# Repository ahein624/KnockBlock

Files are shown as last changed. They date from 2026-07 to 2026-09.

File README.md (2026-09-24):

# AH.knockblock

A phone-controlled office status sign. Tap a button on your phone; the status
instantly shows on two vertically stacked 64×32 HUB75 LED panels, driven as
one 64×64 display by a Raspberry Pi 4.

## Quick start

On a fresh Raspberry Pi with the panel wired up (see [Hardware](#hardware)):

```bash
curl -sSL https://raw.githubusercontent.com/ahein624/KnockBlock/main/install.sh | bash
```

The installer clones the code, builds the panel driver, and installs the
`knockblock` systemd service (it may ask you to reboot once for the audio
change, then re-run). When it finishes, open `http://<pi-ip>:5000` from a
phone on the same WiFi to **claim your sign**: set a password, name it, and
you're live. Re-running the installer later is the upgrade path — it never
touches your password, state, or uploaded media.

Prefer to see every step, or debugging a panel? The full walkthrough is in
[Manual setup](#setup-step-by-step).

## Features

- **Status presets** with emoji icons (On a Call, Free, In a Meeting, Do Not
  Disturb), rendered with auto-fitted text on the panel
- **Custom messages** — type anything (leading emoji becomes the icon), pick a
  background color; recent messages become one-tap chips
- **Custom statuses** — build your own status buttons (up to 8) from text,
  an uploaded image/meme/GIF, or both. Images can play bare or carry a text
  caption; image-only buttons take their name from the file or GIF title.
  They join the status grid with real-render thumbnails, work
  from the Stream Deck (`/api/set/cs_…`), and deleting one that's showing
  releases to auto
- **Auto-revert timers** — "On a Call for 30 min, then back to Free," with a
  live countdown; changing the status keeps the original expiration, even
  across a reload. The phone remembers the selected duration for the next
  hold, and “Forever” has no expiration
- **Live preview** — the phone UI mirrors exactly what the panel shows
- **Device temperature** — Settings shows the Pi CPU temperature in °F
- **Clock & weather screen** — a tappable mode showing the local time plus
  current conditions; outside working hours an idle sign switches to it
  automatically (Open-Meteo, no API key; location auto-detected from the
  Pi's public IP, overridable via settings lat/lon; time follows the Pi's
  system timezone)
- **Brightness control**, **state persistence** across power cycles, and a
  **PWA** phone UI (Add to Home Screen for a full-screen app)
- **Themes** — per-device, in Settings → Appearance: *Glass* (dark,
  translucent, modern), *Workshop* (the warm house style), or *Clear*
  (high-contrast, plain, accessibility-first). Stored in a cookie the
  server reads, so pages load in your theme with no flash
- **Panel styles** — sign-wide, in Settings → Panel style: *Classic* flat
  cards, *Nameplate* (skeuomorphic brushed-metal shop plates — beveled
  edges, corner screws, engraved text, a glowing indicator lamp in the
  status color), *Terminal* (green-phosphor console with scanlines), or
  *8-bit* (pixel icon cards — headset, sun, meeting heads, do-not-enter —
  with the clock and focus screens drawn to match: sun or moon by hour,
  hourglass timer). All original art; the status buttons preview whichever
  is active
- **Password login** — everything (UI and API) requires either a logged-in
  browser session or the API token, so the sign can be exposed beyond the LAN
- **API token for scripts** — one-URL status changes from a Stream Deck,
  Apple Shortcuts, or curl (see below)
- **Screen off** — a prominent “Turn off screen for the day” control below
  the live preview (plus the header shortcut) turns the panel fully dark on
  demand and keeps it off until you turn it back on. It's a top-priority
  manual hold, so it overrides the schedule and whatever's showing; tapping
  any status (or the badge) wakes it. Also at `/api/set/screen_off` for a
  Stream Deck "lights out" button
- **Sleep schedule** — the panel goes dark every night during a configurable
  window (e.g. 22:00–07:00) whenever it's idle; a deliberately set status or
  the manual screen-off override still win. Or pick **Moonlight** instead of
  dark: a very dim night scene — crescent moon, twinkling stars, and a
  sleeping cat exhaling z's
- **On-a-call autodetect** — a tiny agent on your laptop watches the
  camera/mic (macOS via OverSight, Windows via the ConsentStore registry)
  and heartbeats the sign; a 15s watchdog clears the status if the agent
  dies mid-call
- **Focus timer** — 15/25/50-minute buttons; the panel shows FOCUS with a
  live MM:SS countdown, then releases automatically
- **Calendar** — point it at a Google Calendar secret iCal address (no
  OAuth) and the sign shows "In a Meeting" during events, recurring ones
  included
- **GIFs & images** — search Tenor/Giphy and pick from a grid of results,
  or hit Roll for a random one; picks work as panel screens and as custom
  status backgrounds, and you can upload any image or animated GIF from the
  phone. Media rides the manual-hold rules, so the hold TTL and timer chips
  keep a joke from becoming your all-day status. Picked results only ever
  download from the providers' own CDNs. The old public demo keys have gone
  stale, so put a personal (free) key in `auth.json`:
  `{"giphy_key": "..."}` — it's tried first
- **Screen designer** — a pixel editor for the active panel size right in the
  phone UI: draw, flood-fill, undo, start from what the sign is showing,
  save favorites on the device, and send to the panel (rides the same
  manual-hold rules as uploads)
- **Dumpster fire mode** — one tap plays an original procedurally-animated
  "THIS IS FINE." flame scene (no meme copyright, works offline); also at
  `/api/set/dumpster_fire` for a Stream Deck panic button
- **Arcade mode** — an original retro-platformer loop drawn pixel by pixel:
  scrolling bricks, pipes, blinking coins, and a little runner in KnockBlock
  orange who jumps the pipes (no licensed sprites, works offline); also at
  `/api/set/arcade`
- **Demo mode** — share `/demo` and visitors watch the real sign live
  (state, preview, countdowns) but every write is refused with a polite
  quip; secrets (calendar URL, location, API token) are redacted and the
  settings sheet is hidden. Logging in normally exits demo mode
- **Scheduled statuses** — recurring rules like "Lunch, 12:00–13:00,
  Mon–Fri" the sign follows on its own. A rule can show **any screen** — a
  preset, the clock, dumpster fire, arcade, or one of your own custom/GIF
  screens — with overnight windows included. A manual tap overrides; Auto
  resumes
- **Weekly insights** — a "This week" panel with time spent in meetings,
  calls, and focus, from an append-only local history (three months kept,
  message text never logged)
- **First-run claim wizard** — a fresh sign is claimed from a phone on its
  own WiFi: password, name, work hours, API token. No SSH needed
- **Self-update** — an "Update sign" button pulls the latest code, restarts,
  and rolls itself back if the sign doesn't come back up
- **Priority arbiter** — when several sources are active at once:
  manual hold → on-call → focus → calendar → schedule → idle. Manual
  presses release after a configurable TTL (default 2h) so a tapped button
  can't suppress autodetect all day; the Auto button releases a hold early

## Login & security

A fresh sign is **claimed** from its own network: open `http://<pi-ip>:5000`
from a phone on the sign's WiFi and the first-run wizard asks for a
password, a name, and your work hours. The wizard only answers LAN clients
and only while no password exists, so an internet-exposed unclaimed sign
still can't be seized by a stranger. From a terminal (also the only way to
*reset* a forgotten password):

```bash
sudo ./venv/bin/python3 app.py --set-password
```

Claiming also reveals the **API token** used by scripted clients
(`--show-token` reprints it; the phone UI shows it too, with a regenerate
button). Logins get a long-lived session cookie — right for a personal PWA.
Repeated failed logins back off with a per-IP lockout.

**LAN clients skip the password entirely.** A request counts as local only
when every check agrees: the TCP source address is private, no forwarding
headers (`X-Forwarded-For`, `X-Real-IP`, `CF-*`) are present, the source
isn't a known reverse proxy, and the request isn't addressed to the public
hostname. Public traffic that reaches the sign through a proxy on the same
LAN therefore still needs the password. Two optional keys in `auth.json`
configure the site-specific parts:

```json
{"public_host": "sign.example.com", "untrusted_proxies": ["192.168.1.5"]}
```

Set `untrusted_proxies` to the LAN address(es) of whatever relays outside
traffic to the sign (reverse proxy, tunnel daemon), and `public_host` to the
domain it serves.

If you expose the sign to the internet, put it behind HTTPS (a reverse proxy
like Caddy, or a Cloudflare tunnel) — over plain HTTP the password and token
travel in the clear. A Tailscale/VPN-only setup avoids the exposure entirely.

## Remote access

The recommended way to reach the sign away from home is **Tailscale** — no
port forwarding, no reverse proxy, no exposed attack surface:

1. On the Pi: `curl -fsSL https://tailscale.com/install.sh | sh`, then
   `sudo tailscale up`.
2. Install the Tailscale app on your phone and sign in to the same tailnet.
3. Visit `http://<pi-tailscale-name>:5000` (MagicDNS) from anywhere. For
   HTTPS — which lets the phone use the clipboard API and installs more
   cleanly as a PWA — run `sudo tailscale serve --bg 5000` and use the
   `https://…ts.net` URL it prints.

One deliberate quirk: Tailscale addresses live in `100.64.0.0/10`, which is
*not* a private range, so tailnet clients are asked for the password like
any other remote visitor. That's the safe default — anyone you share your
tailnet with shouldn't automatically control your door.

The advanced alternative — a public domain through a reverse proxy or
Cloudflare tunnel — works with the `public_host` / `untrusted_proxies` keys
above; that's how the original sign runs. WiFi captive-portal provisioning
(configuring the Pi's WiFi from the phone) is future work; for now the Pi
joins WiFi the usual way (Raspberry Pi Imager presets or `nmtui`).

## API

Everything the UI does goes through JSON endpoints, so you can script it.
Authenticate with `Authorization: Bearer <token>`, an `X-Api-Token` header,
or `?token=<token>`:

- `GET /api/state` — what's showing and why (`status`, `source`, `held`),
  plus brightness, recents, focus/calendar state, schedules, settings,
  weather
- `POST /api/state` — any subset of:
  `{"status": "free" | "on_a_call" | ... | "clock" | "auto"}` (`auto`
  releases a manual hold),
  `{"message": {"text": "...", "color": "blue"}}`,
  `{"focus_minutes": 25}` (0 cancels),
  `{"brightness": 5-100}`, `{"revert_minutes": N}` (with a status/message;
  0 means forever), `{"preserve_hold": true}` (keep an active hold's absolute
  expiration while changing its status),
  `{"settings": {"sign_name": "Knockblock", "weather_idle": true,
  "work_start": "08:00", "work_end": "18:00", "units": "f", "lat": null,
  "lon": null, "sleep_enabled": true, "sleep_start": "22:00",
  "sleep_end": "07:00", "ical_url": "https://…",
  "manual_ttl_minutes": 120}}`,
  `{"schedules": [{"label": "Lunch", "status": "custom",
  "message": {"text": "Back at 1", "color": "orange"}, "start": "12:00",
  "end": "13:00", "days": [0,1,2,3,4], "enabled": true}]}` — full-list
  replace; `status` is a preset key, `"clock"`, or `"custom"` (which
  requires `message`); `start > end` spans midnight; first matching rule
  wins
- `GET /api/insights?days=7` — seconds per status per local day plus
  totals, from the on-device history (max 31 days; blocked in demo mode)
- `POST /api/statuses` — create a custom status (multipart: `text`, and
  `bg_color` or an image/GIF `file`); `DELETE /api/statuses/<id>` removes
  one (releasing the sign if it's showing). Set them like any status:
  `{"status": "cs_…"}` or `/api/set/cs_…`
- `POST /api/oncall` — `{"active": true|false}` heartbeat from a laptop
  sensor; the status clears itself 15s after the last `true`
- `GET /api/gif/search?q=…` — GIF candidates: `[{"url", "preview", "title"}]`
- `POST /api/gif` — `{"url": "...", "title": "..."}` shows a search pick
  (provider CDNs only), or `{"query": "dancing cat"}` for a random one;
  `revert_minutes` optional on both
- `POST /api/upload` — multipart `file` (image or GIF) plus optional
  `revert_minutes`; shows it on the panel
- `GET|POST /api/set/<status>` — one-URL change for buttons:
  `/api/set/on_a_call?minutes=30`, `/api/set/focus?minutes=25`,
  `/api/set/dumpster_fire`, `/api/set/auto`
- `POST /api/update` / `GET /api/update/status` — start the self-updater /
  watch its progress. Session or LAN only, like `GET|POST /api/token` —
  a leaked API token can't swap code or read credentials
- `GET /preview.png` — PNG of what the panel currently shows

## On-call laptop sensors

Both agents heartbeat `POST /api/oncall` every 5s while the camera or mic
is in use, so a crashed agent just times out after 15s.

**macOS** — install [OverSight](https://objective-see.org/products/oversight.html),
then in OverSight's settings set *Execute Action* to
`agents/oversight-knockblock.sh` (copy it anywhere) and enable *pass
arguments*. Edit the script's `SIGN_URL`/`TOKEN` lines or export
`KNOCKBLOCK_URL`/`KNOCKBLOCK_TOKEN`.

**Windows** — run `agents/knockblock-sensor.ps1` at logon (see the
`schtasks` one-liner in the script header). It polls the same registry keys
Windows uses for the camera/mic tray indicators.

Neither agent needs the token while the laptop is on the sign's LAN, but
set it anyway so the buttons keep working from anywhere.

## Stream Deck

Any Stream Deck action that can hit a URL works — no custom plugin needed.
With the stock **System → Website** action (or the "API Ninja" / "Web
Requests" plugins if you'd rather POST without opening a browser), point a
button at:

```
http://<sign-host>:5000/api/set/on_a_call?token=<your-token>
```

Add `&minutes=30` for "On a Call for 30 minutes, then back to Free". The
same URLs work from Apple Shortcuts ("Get Contents of URL") or cron.

## Hardware

- Raspberry Pi 4 Model B
- Two Waveshare 64×32 HUB75 RGB LED matrix panels, stacked vertically and
  daisy-chained from the first panel's output to the second panel's input
- Generic HUB75 adapter board plugged into the 40-pin GPIO header (no HAT
  level-shifter IC)
- A separate 5V power supply sized for both panels (at least 8A, with power
  delivered to both panels and a common ground). **Do not** power either panel
  from the Pi's 5V pins — the panels can draw more current than the Pi can
  safely supply, and both will brown out.

The app defaults to the two-panel 64×64 layout. It configures a chain length of
2 and the driver's `V-mapper`, with both panels mounted right-side up. To run
the original single-panel 64×32 layout, set `KNOCKBLOCK_PANEL_COUNT=1` in the
service environment before starting KnockBlock. The API, live preview,
thumbnails, uploads, animations, and screen designer all use the active size.

Building an enclosure for the stacked panels? The repository includes a
[parametric case, dimensioned drawing, diffuser specification, and assembly
guide](hardware/case/README.md).

### Two-panel wiring and configuration

Mount both panels right-side up, one above the other. The first panel is the
top half of the finished sign:

```text
Raspberry Pi HUB75 adapter
          │
          ▼
┌────────────────────┐
│ Top panel      IN   │  64×32
│              OUT ──┼────────┐
└────────────────────┘        │
                              ▼
┌────────────────────┐
│ Bottom panel   IN   │  64×32
└────────────────────┘

Logical canvas: 64×64
```

Power both panels directly from the 5V supply. Do not carry panel power
through the Pi or through the HUB75 ribbon cable. Connect the Pi/adapter and
both panels to a common ground. With two panels, inject power into each panel
rather than relying on one panel's power connector to feed the other.

No software setting is needed for the normal two-panel arrangement. On start,
KnockBlock configures the driver with these effective options:

| Option | Value | Purpose |
| --- | --- | --- |
| Physical panel | 64 columns × 32 rows | Size of each Waveshare module |
| Chain length | `2` | Top panel output feeds the bottom panel input |
| Parallel chains | `1` | One HUB75 data chain from the Pi |
| Pixel mapper | `V-mapper` | Presents the horizontal hardware chain as 64×64 |

After wiring the second panel, update and restart the sign, then open Settings.
**Panel style → Display** should read `64×64 · 2 panels`. The live preview and
screen designer should both be square. For a hardware-only check, stop the
service and run:

```sh
sudo systemctl stop knockblock
sudo ./venv/bin/python3 hello_matrix.py
# Press Ctrl+C after checking both halves.
sudo systemctl start knockblock
```

To keep using one panel, add a systemd override:

```sh
sudo systemctl edit knockblock
```

```ini
[Service]
Environment=KNOCKBLOCK_PANEL_COUNT=1
```

Then apply it:

```sh
sudo systemctl daemon-reload
sudo systemctl restart knockblock
```

Remove that override, or change the value to `2`, before moving back to the
stacked display. `KNOCKBLOCK_PANEL_COUNT` accepts only `1` or `2`; an invalid
value deliberately prevents startup instead of driving an unknown layout.

## Updating

Settings → Software → **Update sign** pulls the latest code, restarts the
service, and health-checks itself — if the sign doesn't come back up it
rolls back to the version that worked and says so. Under the hood it's
`scripts/update.sh` run as a transient systemd unit; your password, state,
history, and uploaded media are untracked files the update never touches.
Re-running `install.sh` does the same job from a shell.

## Project layout

- `app.py` — Flask web server; exposes the phone UI and the JSON API
- `auth.py` — password + API-token auth, backed by `auth.json` (not in git)
- `matrix.py` — wraps `rpi-rgb-led-matrix` to render a preset (text + colors) to the panel
- `presets.py` — the status screens (label, text lines, colors) shown as phone buttons
- `history.py` — append-only status history + the insights aggregation
- `templates/` — the phone UI, login, and first-run claim wizard
- `install.sh` / `deploy/` — one-command installer and the systemd unit
- `scripts/update.sh` — the self-updater (fetch, swap, health-check, roll back)
- `hello_matrix.py` — standalone smoke test, no Flask required
- `requirements.txt` — Python deps installed via pip (Flask, Pillow)
- `dev/` — hardware-free dev server (stubbed panel) for UI work

## Development (no hardware needed)

Everything except the physical panel runs on any machine:

```bash
python3 -m venv venv
./venv/bin/pip install -r requirements.txt
./venv/bin/python3 dev/dev_server.py
```

Open http://127.0.0.1:5099 and log in with `devpassword1`. Runtime files
live in `dev/state/` (gitignored), so a real sign's `auth.json` and
`state.json` are never touched. The dev server poses as a public client
so the login and demo flows are exercisable; see the switches documented
at the top of `dev/dev_server.py` (`KNOCKBLOCK_DEV_LOCAL`,
`KNOCKBLOCK_DEV_UNCLAIMED`, `KNOCKBLOCK_DEV_FRESH`).

## Setup, step by step

### 1. Disable onboard audio

The Pi's onboard audio uses the same PWM hardware the LED matrix needs for
clean timing; leaving it enabled causes flicker and ghosting.

Edit the boot config (`/boot/firmware/config.txt` on newer Raspberry Pi OS,
or `/boot/config.txt` on older releases) and comment out or remove the audio
line:

```
# dtparam=audio=on
```

**This requires a reboot** (`sudo reboot`) to take effect.

### 2. Install the driver (hzeller/rpi-rgb-led-matrix)

Current Raspberry Pi OS (Debian trixie) blocks system-wide `pip install`
(PEP 668), so everything Python-related lives in a virtualenv inside the
project folder:

```bash
sudo apt-get update
sudo apt-get install -y git python3-dev python3-pip cython3
git clone https://github.com/hzeller/rpi-rgb-led-matrix.git ~/rpi-rgb-led-matrix
cd ~/KnockBlock
python3 -m venv venv
./venv/bin/pip install --upgrade pip
```

The current version of the driver builds via `pyproject.toml`/CMake and
needs Pillow's internal `Imaging.h` C header, which isn't vendored in the
repo. Install Pillow first, then fetch the matching header (and its own
few includes) into the bindings' `shims/` folder before building:

```bash
./venv/bin/pip install Pillow Flask
PILLOW_VERSION=$(./venv/bin/python3 -c "import PIL; print(PIL.__version__)")
cd ~/rpi-rgb-led-matrix/bindings/python/rgbmatrix/shims
for f in Imaging.h ImPlatform.h Mode.h Arrow.h ImagingUtils.h; do
  curl -sSL -o "$f" "https://raw.githubusercontent.com/python-pillow/Pillow/$PILLOW_VERSION/src/libImaging/$f"
done
cd ~/KnockBlock
./venv/bin/pip install ~/rpi-rgb-led-matrix
```

### 3. Install remaining Python deps

Flask and Pillow already went into the venv above (needed there for the
driver's header check); nothing else is required for `requirements.txt`.

### 4. Confirm the driver imports

```bash
./venv/bin/python3 -c "import rgbmatrix; print('ok')"
```

If this fails, the Python bindings didn't build/install correctly — re-run
step 2 and check the build output.

### 5. Light up a static test screen

Before touching the web app, isolate hardware issues with the standalone
test script. It needs `sudo` for GPIO access:

```bash
sudo ./venv/bin/python3 hello_matrix.py
```

You should see "HELLO" / "KNOCKBLOCK" in green text on the panel.

### 6. Hardware troubleshooting

If the test screen is blank, garbled, flickery, or has wrong colors, adjust
these options in `matrix.py` one at a time and re-run `hello_matrix.py`:

| Symptom | Try |
| --- | --- |
| Panel is completely blank | Check the panel's own power supply is on and wired to the panel (not just the Pi); confirm the ribbon cable orientation; try `hardware_mapping = "adafruit-hat"` if your adapter board has a level-shifter chip |
| Top panel works but bottom panel is blank | Confirm the second panel has its own 5V power connection; check the ribbon from the top panel's `OUT` connector to the bottom panel's `IN`; confirm `KNOCKBLOCK_PANEL_COUNT` is not set to `1` |
| Two halves appear beside each other or only half the picture is useful | Confirm the installed code includes `pixel_mapper_config = "V-mapper"`; Settings should report `64×64 · 2 panels` |
| The top and bottom content are reversed | The panel connected directly to the Pi is the first/top panel. Swap the panel data order, not the power wiring |
| Image is garbled / scrambled pixels | Increase `gpio_slowdown` (try 2, then 3, then 4) — the Pi is driving the GPIO faster than the panel can latch |
| Flickering or dim/ghosting rows | Increase `gpio_slowdown`; confirm onboard audio is disabled (step 1) |
| Colors are swapped (e.g. red/blue flipped) | Change `led_rgb_sequence` from `"RGB"` to `"RBG"`, `"GRB"`, etc. until colors match |

### 7. Set the login password

```bash
sudo ./venv/bin/python3 app.py --set-password
```

Note the API token it prints if you plan to script the sign.

### 8. Run the web app

```bash
sudo ./venv/bin/python3 app.py
```

Find the Pi's IP address with `hostname -I`, then on your phone (same WiFi),
visit `http://<pi-ip-address>:5000`, log in, and tap a button — the panel
should update immediately.

### 9. Auto-start on boot (systemd)

Create `/etc/systemd/system/knockblock.service` (adjust `WorkingDirectory` and
`User` if your project lives somewhere other than `/home/ahein/KnockBlock`):

```ini
[Unit]
Description=KnockBlock status sign
After=network.target

[Service]
Type=simple
WorkingDirectory=/home/ahein/KnockBlock
ExecStart=/home/ahein/KnockBlock/venv/bin/python3 /home/ahein/KnockBlock/app.py
Restart=on-failure
User=root

[Install]
WantedBy=multi-user.target
```

The service runs as `root` because the LED matrix library needs raw GPIO
access, same as the `sudo` used above.

Enable and start it:

```bash
sudo systemctl daemon-reload
sudo systemctl enable knockblock
sudo systemctl start knockblock
```

Check status and logs:

```bash
sudo systemctl status knockblock
sudo journalctl -u knockblock -f
```

## Future work

- **WiFi captive-portal provisioning** — claim a sign that isn't on WiFi
  yet, straight from the phone; today the Pi joins WiFi via the Raspberry
  Pi Imager presets or `nmtui`
- **Tailnet-as-local option** — an opt-in `trusted_networks` key so tailnet
  clients skip the password like LAN clients do
- **Drag-to-reorder schedules** — priority is list order; today it's
  up-arrows

---

*Practical over decorative.*

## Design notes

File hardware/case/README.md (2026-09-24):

# Dual-panel case

This enclosure holds two Waveshare RGB-Matrix-P2.5-64x32 panels vertically so
they read as one 64×64 display. It is sized for the panel sold under Amazon
ASIN `B0BRBGHFKQ`: each module is nominally 160 × 80 mm and about 14.5 mm
deep.

The design does not use the panels' rear mounting holes because the published
specification does not provide their coordinates. The panels sit in a
perimeter cradle and are held with movable clips instead. Measure both of your
panels before committing to a full print.

Dimensioned case drawing

## Design summary

| Item | Nominal dimension |
| --- | ---: |
| Finished face | 180 × 180 mm |
| Finished depth | 62 mm |
| Combined panel face | 160 × 160 mm |
| Panel pocket | 161 × 161 × 16 mm |
| Diffuser | 164 × 164 × 2 mm, 8 mm corner clips |
| Diffuser-to-LED gap | 10 mm |
| Front bezel | 4 mm deep |
| Optical spacer | 10 mm deep |
| Panel cradle | 16 mm deep |
| Rear electronics shell | 32 mm deep |

All dimensions are parameters near the top of
[`knockblock_case.scad`](knockblock_case.scad). The 180 mm square parts fit on
a typical 220 × 220 mm printer bed.

### What to measure first

Use calipers and update the matching parameters in the CAD file:

1. Measure the width and height of both panels. Use the larger value plus
   0.6–1.0 mm for `panel_pocket`.
2. Measure from the LED face to the tallest rear component. Include any power
   plug or ribbon-cable bend that must sit inside the cradle.
3. Measure the actual diffuser thickness. Give its pocket 0.3–0.5 mm of total
   clearance.
4. Lay out the Pi, HUB75 adapter, and cables in the 174 × 174 × 29 mm usable
   rear cavity. Increase `electronics_depth` if the cable bend needs it.

The most important test is the pocket fit. Export and print `fit_coupon`
before printing the full case.

## Parts

### Printed parts

- 1 × `bezel`
- 1 × `spacer`
- 1 × `cradle`
- 1 × `back_shell`
- 1 × `diffuser` only when printing the diffuser instead of cutting opal sheet
- 6–8 × `retainer_clip`
- 1 × `fit_coupon` before the production print

PETG or ASA is preferred. Black material prevents light leaking through the
case. PLA can work for a prototype, but the rear cavity contains a Raspberry
Pi and should not be allowed to soften in a warm room.

Suggested starting settings: 0.2 mm layers, four perimeters, five top/bottom
layers, and 25% infill. Print the flat frames face-down. Orient the back shell
with its wall-facing panel on the build plate. The model avoids large internal
supports, although a printer may request small supports at the bottom cable
notch.

### Purchased parts

- 1 × 164 × 164 × 2 mm opal lighting acrylic or polycarbonate diffuser,
  with each corner clipped 8 × 8 mm to clear the face screws
- 4 × M3 × 35 mm black countersunk machine screws for the face
- 4 × M3 heat-set inserts, sized to match the CAD's 4.2 mm insert holes
- 6–8 × M3 × 8 mm screws and matching inserts for the panel clips
- 1–2 mm self-adhesive closed-cell foam for the clips
- 2 × suitable wall screws and anchors
- 4 × 5 mm rubber wall bumpers to preserve airflow behind the rear vents
- Low-voltage cable strain relief or grommet for the 20 × 10 mm bottom entry

The face screws are intentionally visible and serviceable. If a clean face is
more important than tool-free alignment, move the four fasteners to the sides
before printing.

## Diffuser

A 2 mm opal sheet with roughly 30–50% light transmission is a practical
starting point. The 10 mm air gap is four times the 2.5 mm pixel pitch, which
usually blends adjacent pixels while keeping text reasonably sharp. That gap
is a design recommendation, not a manufacturer specification.

For a printed prototype, open
[`stl/knockblock_diffuser.3mf`](stl/knockblock_diffuser.3mf) directly in Bambu
Studio. The plate contains a 164 × 164 × 2 mm diffuser with 8 mm clipped
corners. Use natural or translucent PETG, no supports, and 0.2 mm layers. A
printed panel is useful for fit and light-gap testing, but cut opal acrylic or
polycarbonate will normally produce more even diffusion.

Test the real material before ordering a finished cut:

- Hold a diffuser sample 8, 10, and 12 mm from a lit panel.
- Check white at high brightness for visible hot spots.
- Check small text at normal viewing distance for excessive blur.
- Change `diffuser_gap` in the CAD if another distance looks better.

Do not use a clear sheet described only as "frosted edge." It needs to diffuse
across its face. Smoked LED acrylic improves black levels but often needs a
thin diffusion film behind it to hide individual LEDs.

## CAD export

Open `knockblock_case.scad` in OpenSCAD 2021.01 or newer. Set `part` near the
top of the file, render with F6, then use **File → Export → Export as STL**.

```scad
part = "fit_coupon";     // print this first
part = "bezel";
part = "diffuser";       // optional printable replacement for opal sheet
part = "spacer";
part = "cradle";
part = "back_shell";
part = "retainer_clip";
part = "assembly";      // exploded preview only
```

The `assembly` view is for inspection and is not printable as a single part.

## Assembly

1. Print the fit coupon. Confirm that the panel thickness fits its channel
   without force and the diffuser sample fits its slot.
2. Deburr the diffuser and clean both faces. Lay it in the rear recess of the
   bezel.
3. Join the bezel and optical spacer. Thin black foam tape around the outside
   edge can stop light leaks; keep tape out of the 160 mm image area.
4. Place both panels face-down in the cradle with their long edges touching.
   Keep both arrows/orientation marks pointed the same way. The top panel's
   output ribbon reaches the bottom panel's input.
5. Add foam-faced retaining clips at clear spots around the rear perimeter.
   Tighten only enough to stop movement. Do not bow the PCBs.
6. Join the front stack to the cradle. Check that the physical seam is straight
   before tightening the four face screws.
7. Mount the Pi and adapter in the rear cavity with printed standoffs,
   commercial adhesive standoffs, or cable ties through the ventilation grid.
   Keep metal parts off the PCB underside.
8. Connect HUB75 data and inject 5 V power separately into both panels. Use a
   common ground as described in the main project README.
9. Put a 5 mm rubber bumper near each rear corner. Attach the rear shell to the
   wall with both keyholes, add a third restraint at the bottom if the sign can
   be bumped, then connect the front assembly. Keep the top and bottom vents
   clear.

## Power and heat

Keep the mains-powered AC/DC supply outside this enclosure. Bring only its
low-voltage 5 V output into the bottom cable entry, use strain relief, and
power each panel with its own adequately sized branch. The case provides rear
vents, but they are not a substitute for checking temperature under a
worst-case bright image.

Before leaving the sign unattended, run a full-white screen for 30 minutes at
the intended brightness. Confirm that the printed case, diffuser, wiring, and
Pi remain within their safe operating temperatures.

## Source dimensions

- [Waveshare product page](https://www.waveshare.com/rgb-matrix-p2.5-64x32.htm)
- [Waveshare documentation](https://docs.waveshare.com/RGB-Matrix-Px-64x32)

The source pages specify a 160 × 80 mm panel, 2.5 mm pitch, 64 × 32 pixels,
5 V input, and up to roughly 12 W per module. The enclosure dimensions above
add fabrication clearance and are not an official Waveshare mechanical
drawing.

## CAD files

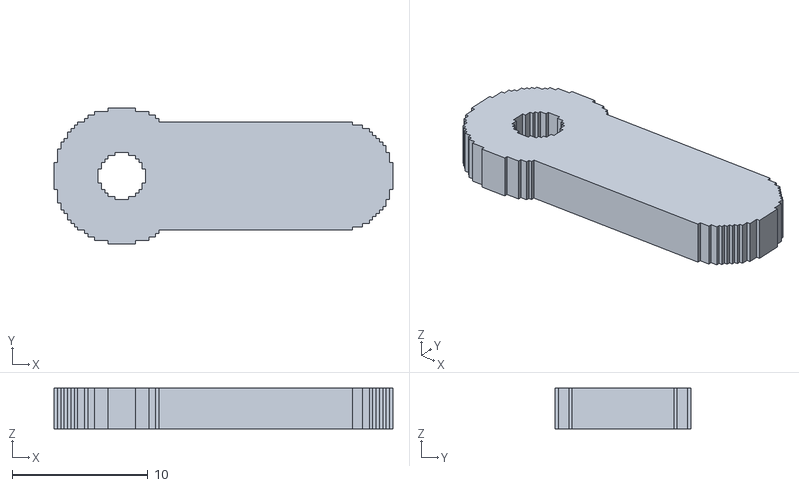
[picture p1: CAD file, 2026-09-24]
hardware/case/stl/knockblock_retainer_clip.stl
25.0 x 10.0 x 3.00

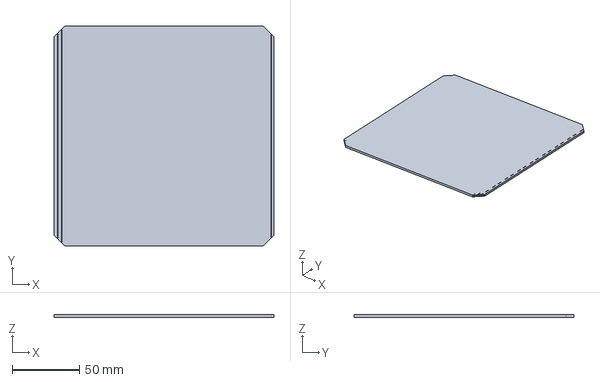
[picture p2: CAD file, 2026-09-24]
hardware/case/stl/knockblock_diffuser.3mf
164.0 x 164.0 x 2.00 mm

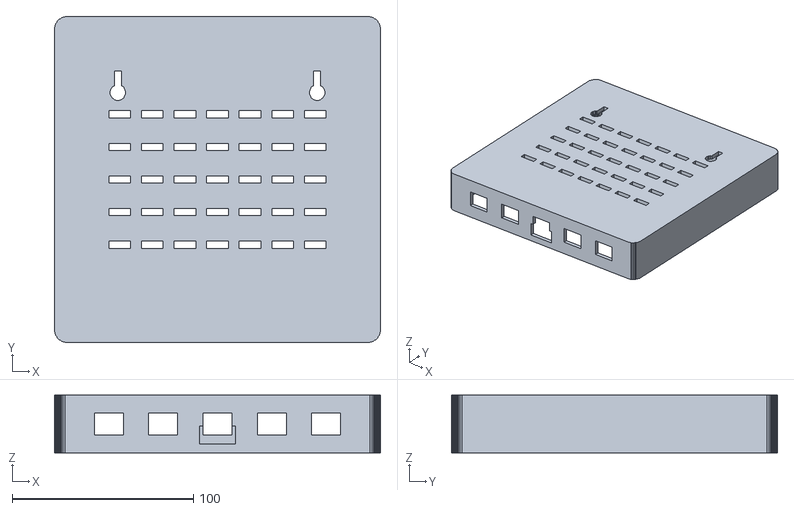
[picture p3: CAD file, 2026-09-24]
hardware/case/stl/knockblock_back_shell.stl
180.0 x 180.0 x 32.0

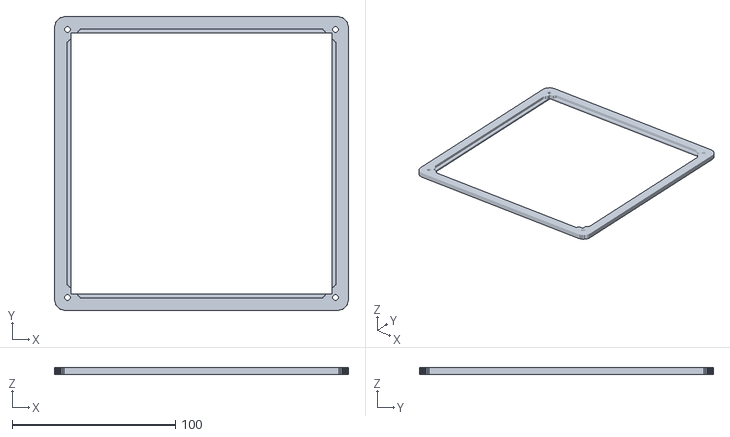
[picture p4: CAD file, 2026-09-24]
hardware/case/stl/knockblock_bezel.stl
180.0 x 180.0 x 4.00

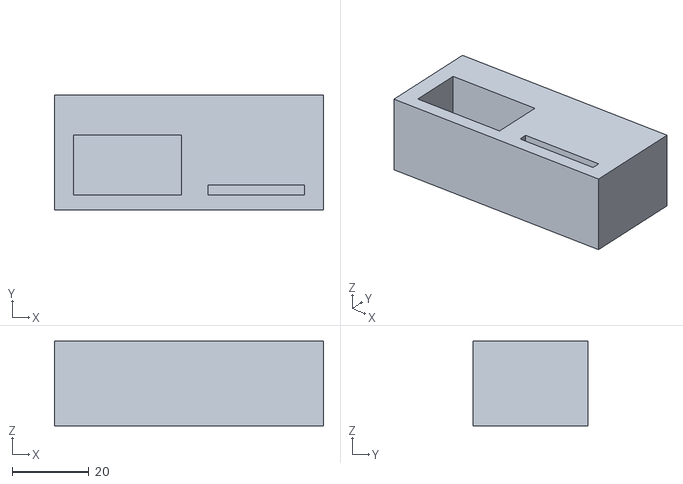
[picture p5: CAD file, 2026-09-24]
hardware/case/stl/knockblock_fit_coupon.stl
70.0 x 30.0 x 22.0

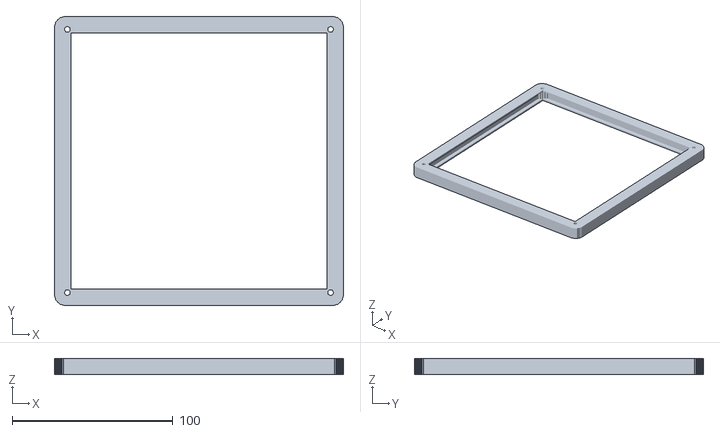
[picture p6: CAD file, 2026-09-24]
hardware/case/stl/knockblock_spacer.stl
180.0 x 180.0 x 10.0

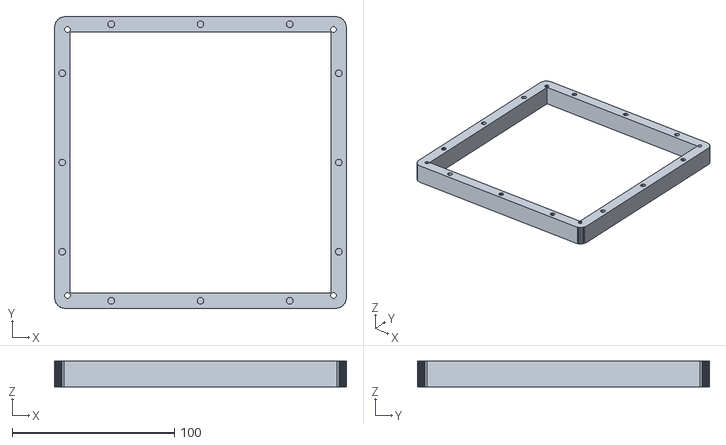
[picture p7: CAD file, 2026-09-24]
hardware/case/stl/knockblock_cradle.stl
180.0 x 180.0 x 16.0

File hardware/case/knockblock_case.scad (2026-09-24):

/*
 * AH.knockblock dual-panel enclosure
 *
 * Two Waveshare RGB-Matrix-P2.5-64x32 modules, stacked vertically.
 * Units are millimetres. Set `part` and export one STL at a time.
 */

part = "assembly"; // assembly, bezel, diffuser, spacer, cradle, back_shell, retainer_clip, fit_coupon

// Measured hardware. Recheck both panels before the production print.
panel_width = 160;
panel_height = 80;
panel_depth = 14.7;
panel_pocket = 161;

// Optical stack.
diffuser_width = 164;
diffuser_thickness = 2;
diffuser_clearance = 0.4;
diffuser_corner_clip = 8;
diffuser_gap = 10;
view_opening = 159.5;

// Case envelope.
case_width = 180;
corner_radius = 7;
bezel_depth = 4;
cradle_depth = 16;
electronics_depth = 32;
wall = 3;

// Hardware clearances. Tune these for your printer and inserts.
face_screw_diameter = 3.4;
face_countersink_diameter = 6.4;
insert_hole_diameter = 4.2;
face_screw_offset = 82;
clip_screw_diameter = 3.4;
clip_insert_diameter = 4.2;

$fn = 48;
epsilon = 0.02;

module rounded_square_2d(size, radius) {
    offset(r = radius)
        square([size - 2 * radius, size - 2 * radius], center = true);
}

module rounded_block(size, depth, radius) {
    linear_extrude(height = depth)
        rounded_square_2d(size, radius);
}

module chamfered_square_2d(size, chamfer) {
    half = size / 2;
    polygon(points = [
        [-half + chamfer, -half], [half - chamfer, -half],
        [half, -half + chamfer], [half, half - chamfer],
        [half - chamfer, half], [-half + chamfer, half],
        [-half, half - chamfer], [-half, -half + chamfer]
    ]);
}

module face_hole(height, countersink = false) {
    translate([0, 0, -epsilon])
        cylinder(d = face_screw_diameter, h = height + 2 * epsilon);
    if (countersink)
        translate([0, 0, -epsilon])
            cylinder(
                d1 = face_countersink_diameter,
                d2 = face_screw_diameter,
                h = 2.1 + epsilon
            );
}

module four_face_holes(height, countersink = false) {
    for (x = [-face_screw_offset, face_screw_offset])
        for (y = [-face_screw_offset, face_screw_offset])
            translate([x, y, 0]) face_hole(height, countersink);
}

module bezel() {
    pocket_depth = diffuser_thickness + diffuser_clearance;
    difference() {
        rounded_block(case_width, bezel_depth, corner_radius);

        // The smaller front opening leaves a narrow ledge that retains the
        // diffuser. The rear pocket gives the sheet replaceable clearance.
        translate([0, 0, -epsilon])
            linear_extrude(height = bezel_depth + 2 * epsilon)
                square([view_opening, view_opening], center = true);
        translate([0, 0, bezel_depth - pocket_depth])
            linear_extrude(height = pocket_depth + epsilon)
                chamfered_square_2d(
                    diffuser_width + diffuser_clearance,
                    diffuser_corner_clip
                );

        four_face_holes(bezel_depth, true);
    }
}

module spacer() {
    retaining_lip = 1.5;
    difference() {
        rounded_block(case_width, diffuser_gap, corner_radius);

        // Narrow front and rear lips retain the diffuser and stop the panels.
        // The middle opens wider so light can spread before reaching the sheet.
        translate([0, 0, -epsilon])
            linear_extrude(height = diffuser_gap + 2 * epsilon)
                square([view_opening, view_opening], center = true);
        translate([0, 0, retaining_lip])
            linear_extrude(height = diffuser_gap - 2 * retaining_lip)
                chamfered_square_2d(diffuser_width + 2, 6);
        four_face_holes(diffuser_gap);
    }
}

module clip_insert_holes() {
    // Select only the positions that avoid connectors on your panel revision.
    positions = [-55, 0, 55];
    edge = (case_width + panel_pocket) / 4;

    for (p = positions) {
        translate([p, edge, cradle_depth - 6])
            cylinder(d = clip_insert_diameter, h = 6 + epsilon);
        translate([p, -edge, cradle_depth - 6])
            cylinder(d = clip_insert_diameter, h = 6 + epsilon);
        translate([edge, p, cradle_depth - 6])
            cylinder(d = clip_insert_diameter, h = 6 + epsilon);
        translate([-edge, p, cradle_depth - 6])
            cylinder(d = clip_insert_diameter, h = 6 + epsilon);
    }
}

module cradle() {
    difference() {
        rounded_block(case_width, cradle_depth, corner_radius);
        translate([0, 0, -epsilon])
            linear_extrude(height = cradle_depth + 2 * epsilon)
                square([panel_pocket, panel_pocket], center = true);
        four_face_holes(cradle_depth);
        clip_insert_holes();
    }
}

module keyhole_cut(depth) {
    // Insert the screw head through the circle, then lower the case so the
    // screw shaft rests in the narrow upper slot.
    union() {
        cylinder(d = 8.5, h = depth);
        translate([-2, 0, 0]) cube([4, 12, depth]);
    }
}

module rear_vent_cut(depth) {
    for (x = [-54, -36, -18, 0, 18, 36, 54])
        for (y = [-36, -18, 0, 18, 36])
            translate([x - 6, y - 2, 0]) cube([12, 4, depth]);
}

module side_vent_cuts() {
    // Bottom inlets and top outlets maintain convection when the rear panel
    // is close to a wall.
    for (x = [-60, -30, 0, 30, 60]) {
        translate([x - 8, case_width / 2 - wall - epsilon, 10])
            cube([16, wall + 2 * epsilon, 12]);
        translate([x - 8, -case_width / 2 - epsilon, 10])
            cube([16, wall + 2 * epsilon, 12]);
    }
}

module back_shell() {
    inner_width = case_width - 2 * wall;
    back_panel = wall;
    boss_radius = 4.5;

    difference() {
        union() {
            difference() {
                rounded_block(case_width, electronics_depth, corner_radius);

                // Open front cavity; leave a solid wall-facing rear panel.
                translate([0, 0, -epsilon])
                    linear_extrude(height = electronics_depth - back_panel + epsilon)
                        rounded_square_2d(
                            inner_width,
                            max(1, corner_radius - wall)
                        );
            }

            // Full-height corner bosses receive inserts from the open front.
            for (x = [-face_screw_offset, face_screw_offset])
                for (y = [-face_screw_offset, face_screw_offset])
                    translate([x, y, 0])
                        cylinder(r = boss_radius, h = electronics_depth);
        }

        // Heat-set insert holes enter from the open front.
        for (x = [-face_screw_offset, face_screw_offset])
            for (y = [-face_screw_offset, face_screw_offset])
                translate([x, y, -epsilon])
                    cylinder(d = insert_hole_diameter, h = 7);

        // Low-voltage cable exit in the bottom wall.
        translate([-10, -case_width / 2 - epsilon, 5])
            cube([20, wall + 2 * epsilon, 10]);

        // Wall-mount keyholes and a ventilation/tie-point grid.
        translate([-55, 48, electronics_depth - back_panel - epsilon])
            keyhole_cut(back_panel + 2 * epsilon);
        translate([55, 48, electronics_depth - back_panel - epsilon])
            keyhole_cut(back_panel + 2 * epsilon);
        translate([0, 0, electronics_depth - back_panel - epsilon])
            rear_vent_cut(back_panel + 2 * epsilon);
        side_vent_cuts();
    }
}

module retainer_clip() {
    // Rotate the long end over a clear section of PCB and add a foam pad.
    difference() {
        hull() {
            translate([-5, 0, 0]) cylinder(d = 10, h = 3);
            translate([11, 0, 0]) cylinder(d = 8, h = 3);
        }
        translate([-5, 0, -epsilon])
            cylinder(d = clip_screw_diameter, h = 3 + 2 * epsilon);
    }
}

module fit_coupon() {
    // Two gauges in one small print: the panel-depth channel on the left
    // and the diffuser slot on the right.
    difference() {
        cube([70, 30, 22]);
        translate([5, 4, 4])
            cube([28, panel_depth + 0.8, 22]);
        translate([40, 4, 4])
            cube([25, diffuser_thickness + diffuser_clearance, 22]);
    }
}

module diffuser_preview() {
    color([0.82, 0.88, 0.9, 0.45])
        translate([0, 0, bezel_depth - diffuser_thickness / 2])
            linear_extrude(height = diffuser_thickness, center = true)
                chamfered_square_2d(diffuser_width, diffuser_corner_clip);
}

module diffuser() {
    linear_extrude(height = diffuser_thickness)
        chamfered_square_2d(diffuser_width, diffuser_corner_clip);
}

module panels_preview(z) {
    color([0.08, 0.08, 0.08]) {
        translate([0, panel_height / 2, z])
            cube([panel_width, panel_height, panel_depth], center = true);
        translate([0, -panel_height / 2, z])
            cube([panel_width, panel_height, panel_depth], center = true);
    }
}

module assembly() {
    explode = 3;
    color("black") bezel();
    diffuser_preview();
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

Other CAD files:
hardware/case/stl/knockblock_diffuser.stl

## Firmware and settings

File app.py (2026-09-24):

"""Flask server that lets a phone control the KnockBlock LED status sign."""
import argparse
import getpass
import ipaddress
import json
import random
import re
import secrets
import shutil
import subprocess
import threading
import time
from datetime import datetime, timedelta
from io import BytesIO
from pathlib import Path

from flask import Flask, jsonify, redirect, render_template, request, send_file, session
from PIL import Image

import auth
import calendar_source
import history
import media
import panel_themes
import weather
from matrix import (
    PANEL_COUNT,
    PANEL_COLS,
    PANEL_ROWS,
    MatrixDisplay,
    build_message_preset,
    compose_preset,
)
from presets import (
    DEFAULT_MESSAGE_COLOR,
    DEFAULT_PRESET,
    FOCUS_STATUS,
    MESSAGE_COLORS,
    PRESETS,
)

STATE_FILE = Path(__file__).resolve().parent / "state.json"
CPU_TEMP_FILE = Path("/sys/class/thermal/thermal_zone0/temp")
MAX_MESSAGE_LENGTH = 80
MAX_SIGN_NAME = 40
MAX_SCHEDULES = 20
MAX_CUSTOM_STATUSES = 8
CUSTOM_STATUS_ID_RE = re.compile(r"^cs_[0-9a-f]{8}$")
MAX_RECENTS = 6
MAX_REVERT_MINUTES = 12 * 60
PREVIEW_SCALE = 6
WEATHER_REFRESH_SECONDS = 15 * 60
CALENDAR_REFRESH_SECONDS = 5 * 60
# 1s tick: the focus countdown repaints every second; everything else is a
# no-op signature comparison, so the fast tick costs almost nothing.
SCHEDULER_INTERVAL = 1
# The on-call sensor heartbeats every ~5s; if beats stop (agent crashed,
# laptop asleep) the status clears itself this many seconds later.
ONCALL_TTL = 15
TIME_RE = re.compile(r"^([01]\d|2[0-3]):[0-5]\d$")

DEFAULT_SETTINGS = {
    "sign_name": "Knockblock",
    "panel_theme": "classic",  # how preset statuses render on the panel
    "weather_idle": True,
    "work_start": "08:00",
    "work_end": "18:00",
    "work_days": [0, 1, 2, 3, 4],  # Mon-Fri
    "units": "f",
    "lat": None,  # None = auto-detect from public IP
    "lon": None,
    "sleep_enabled": False,
    "sleep_start": "22:00",
    "sleep_end": "07:00",
    "sleep_scene": "dark",  # "dark" = panel off, "moon" = dim night scene
    "ical_url": None,  # Google Calendar secret iCal address
    "manual_ttl_minutes": 120,  # 0 = manual presses hold forever
}

# All black; what the panel shows during scheduled sleep.
SLEEP_PRESET = {"lines": [], "bg_color": (0, 0, 0)}

# What demo visitors get instead of side effects.
DEMO_QUIPS = [
    "Demo mode: admired, not altered.",
    "Nice tap. The hardware respectfully declines.",
    "The sign remains under Andrew's exclusive jurisdiction.",
    "Look with your eyes, not with your HTTP requests.",
]

LOGIN_FREE_ATTEMPTS = 3
LOGIN_LOCK_SECONDS = 30
LOGIN_LOCK_MAX = 600

app = Flask(__name__)
app.secret_key = auth.secret_key()
app.config["MAX_CONTENT_LENGTH"] = media.MAX_UPLOAD_BYTES
app.config["PERMANENT_SESSION_LIFETIME"] = timedelta(days=180)
app.config["SESSION_COOKIE_SAMESITE"] = "Lax"
display = None  # MatrixDisplay, created in main() — needs GPIO/root
lock = threading.Lock()
login_attempts = {}  # ip -> (failure count, last failure timestamp)
weather_data = None
calendar_events = []  # last good fetch: [(start_ts, end_ts, summary), ...]
calendar_fetched = 0
render_signature = None
media_frames = None  # [(panel-sized RGB frame, seconds), ...] for status "media"
media_generation = 0  # bumps when new media is set, so playback restarts

# The sign shows whichever *source* wins arbitration (see _arbitrate):
#   manual  — a tapped button or custom message, held until `until` passes
#             (None = forever); `explicit` means the user picked the timer,
#             so the UI shows a countdown for it
#   oncall  — laptop sensor heartbeats; active while now < oncall_until
#   focus   — focus timer; panel counts down MM:SS until `until`
#   calendar— an event from the iCal feed is happening now
#   idle    — the default preset (plus the clock/sleep behavior)
state = {
    "manual": None,  # {"status", "message", "until", "explicit"}
    "focus": None,  # {"until": epoch, "minutes": original duration}
    "oncall_until": None,
    "brightness": 70,
    "recents": [],
    "schedules": [],  # recurring rules; see _valid_schedule for the shape
    "custom_statuses": [],  # user-made: {"id","text"} + "bg" color or "file" flag
    "settings": dict(DEFAULT_SETTINGS),
}


def _custom_status(status_id):
    for entry in state["custom_statuses"]:
        if entry["id"] == status_id:
            return entry
    return None


def _valid_color(color):
    return color if color in MESSAGE_COLORS else DEFAULT_MESSAGE_COLOR


def _valid_message(message):
    if isinstance(message, dict) and message.get("text"):
        return {
            "text": str(message["text"])[:MAX_MESSAGE_LENGTH],
            "color": _valid_color(message.get("color")),
        }
    return None


def _valid_schedule(rule):
    """Normalize one recurring-schedule rule, or None if it's unusable.

    Shape: {"id", "enabled", "label", "status", "message", "start", "end",
    "days"} — status is a preset key, "clock", or "custom" (which requires
    a message). start > end means the window spans midnight and belongs to
    the day it starts on. start == end is rejected rather than meaning
    "all day" — an always-on rule is just a status.
    """
    if not isinstance(rule, dict):
        return None
    status = rule.get("status")
    message = _valid_message(rule.get("message")) if status == "custom" else None
    if status == "custom":
        if message is None:
            return None
    elif status not in list(PRESETS) + ["clock", "dumpster_fire", "arcade"]:
        # Any screen can be scheduled — including user-made ones.
        if not (isinstance(status, str) and _custom_status(status) is not None):
            return None
    start, end = rule.get("start"), rule.get("end")
    if not (isinstance(start, str) and TIME_RE.match(start)
            and isinstance(end, str) and TIME_RE.match(end) and start != end):
        return None
    if not isinstance(rule.get("days"), list):
        return None
    days = sorted({d for d in rule["days"] if isinstance(d, int) and 0 <= d <= 6})
    if not days:
        return None
    rule_id = rule.get("id")
    if not (isinstance(rule_id, str) and re.fullmatch(r"[0-9a-f]{8}", rule_id)):
        rule_id = secrets.token_hex(4)
    return {
        "id": rule_id,
        "enabled": bool(rule.get("enabled", True)),
        "label": str(rule.get("label") or "").strip()[:MAX_SIGN_NAME],
        "status": status,
        "message": message,
        "start": start,
        "end": end,
        "days": days,
    }


def _load_state():
    try:
        saved = json.loads(STATE_FILE.read_text())
    except (FileNotFoundError, ValueError):
        return

    # Custom statuses first: the manual-hold check below may point at one.
    entries = saved.get("custom_statuses")
    if isinstance(entries, list):
        kept = []
        for entry in entries:
            if not (isinstance(entry, dict)
                    and isinstance(entry.get("id"), str)
                    and CUSTOM_STATUS_ID_RE.match(entry["id"])
                    and isinstance(entry.get("text"), str) and entry["text"].strip()):
                continue
            text = entry["text"].strip()[:MAX_SIGN_NAME]
            if entry.get("file"):
                if media.status_media_path(entry["id"]) is None:
                    continue  # background image is gone; drop the status
                loaded = {"id": entry["id"], "text": text, "file": True}
                if entry.get("caption") is False:
                    loaded["caption"] = False
                kept.append(loaded)
            else:
                kept.append({"id": entry["id"], "text": text,
                             "bg": _valid_color(entry.get("bg"))})
        state["custom_statuses"] = kept[:MAX_CUSTOM_STATUSES]

    global media_frames
    manual = saved.get("manual")
    if isinstance(manual, dict):
        status = manual.get("status")
        message = _valid_message(manual.get("message"))
        until = manual.get("until")
        ok = (status in list(PRESETS) + ["clock", "dumpster_fire", "arcade", "screen_off"]
              or (status == "custom" and message)
              or (isinstance(status, str) and _custom_status(status) is not None))
        if status == "media":
            media_frames = media.load_current()
            ok = media_frames is not None
        if ok:
            info = manual.get("media")
            state["manual"] = {
                "status": status,
                "message": message if status == "custom" else None,
                "media": info if status == "media" and isinstance(info, dict) else None,
                "until": until if isinstance(until, (int, float)) else None,
                "explicit": bool(manual.get("explicit")),
            }
    elif "status" in saved:  # legacy schema: top-level status/message/revert_at
        status = saved.get("status")
        if status == "off":
            status = "clock"
        message = _valid_message(saved.get("message"))
        revert_at = saved.get("revert_at")
        until = revert_at if isinstance(revert_at, (int, float)) else None
        if status in list(PRESETS) + ["clock"] and status != DEFAULT_PRESET:
            state["manual"] = {
                "status": status, "message": None, "until": until, "explicit": until is not None,
            }
        elif status == "custom" and message:
            state["manual"] = {
                "status": "custom", "message": message, "until": until, "explicit": until is not None,
            }

    focus = saved.get("focus")
    if isinstance(focus, dict) and isinstance(focus.get("until"), (int, float)):
        minutes = focus.get("minutes")
        state["focus"] = {
            "until": focus["until"],
            "minutes": minutes if isinstance(minutes, int) else 0,
        }
    if isinstance(saved.get("oncall_until"), (int, float)):
        state["oncall_until"] = saved["oncall_until"]

    if isinstance(saved.get("brightness"), int) and 5 <= saved["brightness"] <= 100:
        state["brightness"] = saved["brightness"]
    recents = saved.get("recents")
    if isinstance(recents, list):
        state["recents"] = [
            {
                "text": str(entry["text"])[:MAX_MESSAGE_LENGTH],
                "color": _valid_color(entry.get("color")),
            }
            for entry in recents
            if isinstance(entry, dict) and entry.get("text")
        ][:MAX_RECENTS]
    schedules = saved.get("schedules")
    if isinstance(schedules, list):
        rules = [_valid_schedule(rule) for rule in schedules]
        state["schedules"] = [rule for rule in rules if rule][:MAX_SCHEDULES]

    settings = saved.get("settings")
    if isinstance(settings, dict):
        merged = dict(DEFAULT_SETTINGS)
        for key in ("weather_idle", "sleep_enabled"):
            if isinstance(settings.get(key), bool):
                merged[key] = settings[key]
        for key in ("work_start", "work_end", "sleep_start", "sleep_end"):
            if isinstance(settings.get(key), str) and TIME_RE.match(settings[key]):
                merged[key] = settings[key]
        if isinstance(settings.get("work_days"), list):
            days = sorted({d for d in settings["work_days"] if isinstance(d, int) and 0 <= d <= 6})
            if days:
                merged["work_days"] = days
        if settings.get("units") in ("f", "c"):
            merged["units"] = settings["units"]
        for key in ("lat", "lon"):
            if isinstance(settings.get(key), (int, float)):
                merged[key] = settings[key]
        url = settings.get("ical_url")
        if isinstance(url, str) and url.startswith(("http://", "https://")):
            merged["ical_url"] = url
        ttl = settings.get("manual_ttl_minutes")
        if isinstance(ttl, int) and 0 <= ttl <= MAX_REVERT_MINUTES:
            merged["manual_ttl_minutes"] = ttl
        name = settings.get("sign_name")
        if isinstance(name, str) and name.strip():
            merged["sign_name"] = name.strip()[:MAX_SIGN_NAME]
        if settings.get("panel_theme") in panel_themes.PANEL_THEMES:
            merged["panel_theme"] = settings["panel_theme"]
        if settings.get("sleep_scene") in ("dark", "moon"):
            merged["sleep_scene"] = settings["sleep_scene"]
        state["settings"] = merged


def _save_state():
    tmp = STATE_FILE.with_suffix(".tmp")
    tmp.write_text(json.dumps(state))
    tmp.replace(STATE_FILE)


def _in_window(start, end, now):
    current = now.strftime("%H:%M")
    if start <= end:
        return start <= current < end
    return current >= start or current < end  # overnight span


def _in_work_hours(now=None):
    settings = state["settings"]
    now = now or datetime.now()
    if now.weekday() not in settings["work_days"]:
        return False
    return _in_window(settings["work_start"], settings["work_end"], now)


def _active_schedule(now=None):
    """First enabled rule whose window covers now — list order is priority.

    An overnight window (start > end) belongs to the day it starts on: a
    Mon 22:00–02:00 rule matches Monday evening and Tuesday morning."""
    now = now or datetime.now()
    current = now.strftime("%H:%M")
    weekday = now.weekday()
    yesterday = (weekday - 1) % 7
    for rule in state["schedules"]:
        if not rule["enabled"]:
            continue
        if rule["status"].startswith("cs_") and _custom_status(rule["status"]) is None:
            continue  # its screen was deleted underneath it
        if rule["start"] <= rule["end"]:
            if weekday in rule["days"] and rule["start"] <= current < rule["end"]:
                return rule
        else:
            if weekday in rule["days"] and current >= rule["start"]:
                return rule
            if yesterday in rule["days"] and current < rule["end"]:
                return rule
    return None


def _schedule_end_ts(rule, now_ts):
    """Epoch when the currently-active rule's window closes."""
    now = datetime.fromtimestamp(now_ts)
    hour, minute = map(int, rule["end"].split(":"))
    end = now.replace(hour=hour, minute=minute, second=0, microsecond=0)
    if end <= now:  # overnight window still running: it closes tomorrow
        end += timedelta(days=1)
    return end.timestamp()


def _arbitrate(now):
    """Decide what the sign shows. Highest-priority active source wins:
    manual hold → on-call → focus timer → calendar → schedule → idle.

    Returns (source, status, message, countdown_until). Expired holds and
    timers are cleared as a side effect, so callers must hold the lock.
    """
    manual = state["manual"]
    if manual and manual["until"] is not None and now >= manual["until"]:
        state["manual"] = manual = None
    if manual:
        until = manual["until"] if manual["explicit"] else None
        return "manual", manual["status"], manual["message"], until
    if state["oncall_until"] is not None and now >= state["oncall_until"]:
        state["oncall_until"] = None  # watchdog: heartbeats stopped
    if state["oncall_until"]:
        return "oncall", "on_a_call", None, None
    focus = state["focus"]
    if focus and now >= focus["until"]:
        state["focus"] = focus = None
    if focus:
        return "focus", "focus", None, focus["until"]
    if calendar_source.current(calendar_events, now):
        return "calendar", "in_a_meeting", None, None
    rule = _active_schedule(datetime.fromtimestamp(now))
    if rule:
        return "schedule", rule["status"], rule["message"], _schedule_end_ts(rule, now)
    return "idle", DEFAULT_PRESET, None, None


def _set_manual(status, message, revert_minutes, media_info=None, preserve_hold=False):
    """Install a manual hold. An explicit timer wins; otherwise the default
    TTL applies so a tapped button doesn't suppress autodetect all day.
    Phone status changes can keep an existing hold's absolute expiry."""
    now = time.time()
    current = state["manual"]
    current_until = current.get("until") if current else None
    current_active = current is not None and (
        current_until is None or current_until > now
    )
    if preserve_hold and current_active:
        until = current_until
        explicit = bool(current.get("explicit"))
    elif revert_minutes is not None:
        until = now + revert_minutes * 60 if revert_minutes else None
        explicit = True
    elif status == "screen_off":
        # A blackout stays until you turn it back on — never auto-reverts
        # on the default TTL (a dark hallway shouldn't relight itself).
        until, explicit = None, False
    else:
        ttl = state["settings"]["manual_ttl_minutes"]
        until, explicit = (time.time() + ttl * 60 if ttl else None), False
    state["manual"] = {
        "status": status, "message": message, "media": media_info,
        "until": until, "explicit": explicit,
    }


def _set_media(frames, media_info, revert_minutes, preserve_hold=False):
    global media_frames, media_generation
    media_frames = frames
    media_generation += 1
    _set_manual("media", None, revert_minutes, media_info, preserve_hold)


def _idle_clock_active(source, now=None):
    """After hours with nobody claiming the sign → show the clock screen."""
    return (
        state["settings"]["weather_idle"]
        and source == "idle"
        and not _in_work_hours(now)
    )


def _sleeping(source, status, now=None):
    """Scheduled panel rest. Only idle screens (idle default, clock) go
    dark — calls, focus, meetings, and held statuses still show."""
    settings = state["settings"]
    return (
        settings["sleep_enabled"]
        and (source == "idle" or status == "clock")
        and _in_window(settings["sleep_start"], settings["sleep_end"], now or datetime.now())
    )


def _focus_countdown(now):
    left = max(0, int(round(state["focus"]["until"] - now))) if state["focus"] else 0
    return f"{left // 60}:{left % 60:02d}"


_last_logged = None


def _record_transition(source, status):
    """One history line per arbitration outcome change (caller holds lock)."""
    global _last_logged
    if (source, status) != _last_logged:
        _last_logged = (source, status)
        try:
            history.append(source, status)
        except OSError:
            pass  # a full SD card shouldn't take down rendering


def _render_current(force=False):
    """Render whatever should be on the panel now; skips no-op repaints."""
    global render_signature
    now_dt = datetime.now()
    source, status, message, _ = _arbitrate(time.time())
    _record_transition(source, status)
    if _sleeping(source, status, now_dt):
        signature = ("sleep", state["settings"]["sleep_scene"])
    elif status == "screen_off":
        signature = ("off",)
    elif status == "media":
        signature = ("media", media_generation)
    elif status == "dumpster_fire":
        signature = ("fire", media.fire_gif_mtime())
    elif status == "arcade":
        signature = ("arcade",)
    elif status == "custom":
        signature = ("custom", message["text"], message["color"])
    elif status == "focus":
        signature = ("focus", _focus_countdown(time.time()))
    elif _custom_status(status) is not None:
        entry = _custom_status(status)
        backdrop = (media.status_media_path(status).stat().st_mtime
                    if entry.get("file") else entry.get("bg"))
        signature = ("cstatus", status, entry["text"], backdrop)
    elif status == "clock" or _idle_clock_active(source, now_dt):
        signature = (
            "clock",
            now_dt.strftime("%H:%M"),
            weather_data["temp"] if weather_data else None,
            weather_data["code"] if weather_data else None,
            state["settings"]["panel_theme"],
        )
    else:
        signature = ("preset", status, state["settings"]["panel_theme"])

    if not force and signature == render_signature:
        return
    render_signature = signature

    if signature[0] == "sleep":
        if signature[1] == "moon":
            display.play_frames(media.quiet_frames())
        else:
            display.render_preset(SLEEP_PRESET)
    elif signature[0] == "off":
        display.render_preset(SLEEP_PRESET)
    elif signature[0] == "media":
        display.play_frames(media_frames or [])
    elif signature[0] == "fire":
        display.play_frames(media.fire_frames())
    elif signature[0] == "arcade":
        display.play_frames(media.arcade_frames())
    elif signature[0] == "custom":
        display.render_preset(build_message_preset(message["text"], message["color"]))
    elif signature[0] == "focus":
        if state["settings"]["panel_theme"] == "eightbit":
            display.play_frames([(panel_themes.eightbit_focus(signature[1]), 1.0)])
        else:
            display.render_preset({**FOCUS_STATUS, "lines": ["FOCUS", signature[1]]})
    elif signature[0] == "cstatus":
        entry = _custom_status(status)
        if entry.get("file"):
            display.play_frames(media.status_frames(entry) or [])
        else:
            display.render_preset(build_message_preset(entry["text"], entry["bg"]))
    elif signature[0] == "clock":
        if signature[4] == "eightbit":
            display.play_frames([(panel_themes.eightbit_clock(weather_data, now_dt), 1.0)])
        else:
            display.render_preset(weather.clock_preset(weather_data, now_dt))
    elif signature[2] == "classic":
        display.render_preset(PRESETS[status])
    else:
        # A themed preset is a composed scene; a one-frame "animation"
        # shows it and stops whatever was looping before.
        display.play_frames([(panel_themes.compose(PRESETS[status], signature[2], status), 1.0)])
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

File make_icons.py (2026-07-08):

"""Generate the PWA app icons into static/.

Run once after deploying (any machine with Pillow):
    ./venv/bin/python3 make_icons.py

The icon is the AH. monogram over a row of dots — a nod to the LED panel
itself, in the app's warm field palette (olive, tan, parchment, orange).
"""
import os
from pathlib import Path

from PIL import Image, ImageDraw, ImageFont

STATIC_DIR = Path(__file__).resolve().parent / "static"
DOT_COLORS = ["#57543E", "#C9B48F", "#EFE7D6", "#E85D26"]
BACKGROUND = "#221A12"
FONT_CANDIDATES = [
    "/usr/share/fonts/truetype/dejavu/DejaVuSans-Bold.ttf",
    "/System/Library/Fonts/Supplemental/Arial Bold.ttf",
    "/Library/Fonts/Arial Bold.ttf",
]


def _font(size):
    for path in FONT_CANDIDATES:
        if os.path.exists(path):
            return ImageFont.truetype(path, size)
    return ImageFont.load_default()


def draw_icon(size, rounded=True):
    image = Image.new("RGBA", (size, size), (0, 0, 0, 0))
    draw = ImageDraw.Draw(image)
    radius = int(size * 0.22) if rounded else 0
    draw.rounded_rectangle([0, 0, size - 1, size - 1], radius=radius, fill=BACKGROUND)

    # "AH." monogram, slightly above center.
    font = _font(int(size * 0.34))
    bbox = draw.textbbox((0, 0), "AH.", font=font)
    text_w, text_h = bbox[2] - bbox[0], bbox[3] - bbox[1]
    draw.text(
        ((size - text_w) / 2 - bbox[0], size * 0.42 - text_h / 2 - bbox[1]),
        "AH.",
        font=font,
        fill="#C9B48F",
    )

    # Status-color dots underneath, like a lit pixel row.
    dot_radius = size * 0.052
    spacing = size * 0.16
    start_x = size / 2 - spacing * 1.5
    cy = size * 0.70
    for i, color in enumerate(DOT_COLORS):
        cx = start_x + spacing * i
        draw.ellipse(
            [cx - dot_radius, cy - dot_radius, cx + dot_radius, cy + dot_radius],
            fill=color,
        )
    return image


def main():
    STATIC_DIR.mkdir(exist_ok=True)
    draw_icon(512).save(STATIC_DIR / "icon-512.png")
    draw_icon(192).save(STATIC_DIR / "icon-192.png")
    # iOS applies its own corner rounding and dislikes transparency.
    draw_icon(180, rounded=False).convert("RGB").save(STATIC_DIR / "apple-touch-icon.png")
    print(f"Icons written to {STATIC_DIR}")


if __name__ == "__main__":
    main()

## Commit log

2026-07-03 KnockBlock: phone-controlled LED office status sign
    Raspberry Pi 4 + 64x32 HUB75 matrix. Flask PWA with status presets,
    emoji rendering, custom messages, auto-revert timers, live panel
    preview, after-hours weather, brightness control, and persistence.
    [app.py, hello_matrix.py, make_icons.py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]
2026-07-03 Replace Panel Off with a clock & weather screen
    The old blank-panel mode becomes a tappable Clock & Weather status
    (local time + conditions), and the after-hours idle screen shows the
    same view instead of plain weather. Old "off" status is accepted from
    stale clients and mapped to "clock".
    [app.py, weather.py]
2026-07-04 Add password login, API token for Stream Deck, and sleep schedule
    - Password auth (auth.py, auth.json): set via app.py --set-password,
    long-lived session cookie for the PWA, per-IP login backoff
    - API token accepted as Bearer/X-Api-Token header or ?token= query;
    shown in a new UI card with copy/regenerate
    - GET/POST /api/set/<status>?minutes=N for one-URL Stream Deck buttons
    - Scheduled sleep window blanks the panel when idle; explicit statuses
    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
2026-07-04 Redesign the phone UI: settings sheet, optimistic taps, glass styling
    - Primary actions (preview, timer, statuses, message) fill the first
    screen; all set-and-forget settings move to a bottom sheet behind a
    gear button
    - Status taps render optimistically and reconcile with the server
    response; failures roll back via a state re-sync
    - Message input clears on send, submits on Enter, iMessage-style
    composer with inline send button
    - Glassy translucent surfaces, ambient background, status-colored glow
    behind the panel preview, springy micro-interactions,
    prefers-reduced-motion respected
    - Login page restyled to match
2026-07-04 Skip the password for direct LAN clients
    A request is local only when every layer agrees: private TCP source,
    no proxy/forwarding headers, source not a configured reverse proxy
    (auth.json untrusted_proxies), and Host not the configured public_host.
    Public traffic arrives via an on-LAN reverse proxy, so a private source
    address alone proves nothing.
    [app.py, auth.py]
2026-07-04 Add on-call autodetect, priority arbiter, focus timer, and calendar
    - POST /api/oncall {"active": bool} heartbeat endpoint; a 15s watchdog
    clears the status when beats stop, so a crashed agent can't wedge the
    sign. Laptop sensors included: macOS OverSight hook script and a
    Windows ConsentStore poller (agents/)
    - One arbiter decides what shows: manual hold -> on-call -> focus ->
    calendar -> idle. Manual presses hold for a TTL (default 2h,
    settable; Timer chips override per press); an Auto button releases a
    hold early. All expiries are timestamps evaluated on a 1s scheduler
    tick, replacing the threading.Timer revert machinery
    - Focus timer (15/25/50m chips): panel shows FOCUS wit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
    [app.py, calendar_source.py, presets.py]
2026-07-06 Rebrand to AH.knockblock; add random GIFs and image upload
    - AH. monogram branding across the app: wordmark badge in the header
    and login page, new PWA icon (AH. over the four status dots),
    manifest name/colors
    - MatrixDisplay learns play_frames(): a playback thread loops GIF
    frames until the next render; all panel writes now go through an
    internal lock
    - media.py: normalizes uploads/downloads to 64x32 frames (cover-crop,
    frame cap, duration clamp), persists media/current.* so the shown
    GIF survives restarts, and fetches random GIFs from Tenor with a
    Giphy fallback (public demo keys, no signup)
    - POST /api/gif {query?, revert_minutes?} and POST /api/upload
    (multipart) put med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
    [app.py, make_icons.py, matrix.py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]
2026-07-07 Prefer a personal Giphy key from auth.json for GIF fetches
    The public demo keys stay as fallbacks, but auth.json {"giphy_key": ...}
    is tried first so the dice button doesn't depend on their continued
    existence. The key lives with the other site-specific secrets, not in
    git.
    [auth.py, media.py]
2026-07-07 Add dumpster fire mode: THIS IS FINE over procedural flames
    A one-tap mode (UI button + /api/set/dumpster_fire) that plays an
    original heat-diffusion flame animation with "THIS IS FINE." and the
    dog emoji on the panel. Generated once and cached (28 frames, seeded),
    so it works offline and carries no meme-artwork copyright. It's a
    manual hold like any other status: hold TTL, timer chips, and Auto all
    apply.
2026-07-07 Let media/fire.gif replace the procedural dumpster fire flames
    Dumpster fire mode plays media/fire.gif when the file exists (mtime-
    cached, hot-swappable without a restart) and falls back to the
    generated flames otherwise. The GIF itself stays out of git with the
    rest of media/.
    [app.py, media.py]
2026-07-07 Letterbox media instead of cover-cropping
    Scale GIFs/images to fit inside 64x32 preserving aspect ratio, centered
    on black — unlit pixels read as bezel on an LED panel, so the full frame
    shows with nothing cropped away.
2026-07-08 Restyle the phone UI on the AH Field System (webbing grid)
    Canvas/coyote palette, Barlow + IBM Plex Mono, mono spec labels, and a
    single hi-vis orange per view: the dumpster-fire ripcord in the app, the
    UNLOCK button on the login page. Status pill becomes a NOW SHOWING line
    with the hold countdown; clock & weather moves to the footer; PWA icons
    and manifest rebranded. All controls and endpoints unchanged.
2026-07-08 Adopt the Knockblock Final design: warm serif restyle with roomier sections
    Second pass on the redesign, from the "Knockblock Final" Claude Design
    export. Bitter serif display + Barlow body on a warm brown ground; tan
    primary buttons; orange now marks whatever is active (current status,
    selected hold chip, the held badge). Friendlier copy throughout —
    sentence-case statuses, "Hold it there", "Say something", and the
    "PRACTICAL OVER DECORATIVE" footer. Sections sit 24px apart.
    The design drops the old Auto bar, so releasing a hold moved to the
    orange "held" badge (which carries the revert countdown) and the hold
    section's "Back to auto now" subtitle. Clock & weather became a
    full-width row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
    [make_icons.py, presets.py]
2026-07-09 Add a hardware-free dev harness under dev/
    dev/dev_server.py runs the app on :5099 with a stubbed rgbmatrix module
    and all runtime files redirected to dev/state/, so UI work never needs a
    panel or touches a real sign's auth/state. Env switches cover the login,
    claim, and fresh-state flows.
2026-07-09 Add a LAN-only first-run claim wizard at /setup
    A fresh sign can now be claimed from a phone on its own WiFi: set a
    password, name the sign, pick units and work hours, and get the API
    token — no SSH needed. The wizard only exists while no password is set
    and only answers LAN clients, so an internet-exposed unclaimed sign
    still can't be seized; --set-password stays as the fallback and the
    only reset path. Sign name is a new setting, editable from the settings
    sheet, shown in the wordmark and title.
    [app.py]
2026-07-09 Add install.sh: one-command Pi install
    Clones the repo (making the install a proper git clone — the foundation
    for self-update), builds the rgbmatrix bindings with the Pillow header
    shim, disables onboard audio in the boot config (reboot stays manual),
    and installs the systemd unit from deploy/knockblock.service.in. Ends by
    pointing at the claim wizard. Idempotent; --dry-run prints the commands.
2026-07-09 Add self-update: Update sign button, /api/update, rollback script
    scripts/update.sh fetches origin/main, resets the clone, reinstalls deps
    if requirements changed, restarts the service, and health-checks it —
    rolling back to the previous SHA if the sign doesn't come back. Progress
    lands in update_status.json. POST /api/update launches it detached via
    systemd-run (session-or-local only, like /api/token — a leaked API token
    can't swap code); GET /api/update/status relays progress plus the
    running version, which the settings sheet shows next to the button.
    [app.py]
2026-07-09 Document remote access (Tailscale first) and the claim flow
    README gains a Remote access section — Tailscale as the recommended
    no-port-forwarding path, with the CGNAT caveat (tailnet clients aren't
    LAN, so they still log in), and the reverse-proxy keys as the advanced
    route. Login section now leads with the claim wizard. The dev harness
    also gets a guard so the Update button can't reset the dev checkout.
2026-07-09 Add scheduled recurring statuses
    Rules like "Lunch, 12:00-13:00, Mon-Fri" now drive the sign on their
    own: a new arbiter source between calendar and idle, so calls, focus,
    and meetings still outrank a schedule, and a manual tap overrides it
    (Auto resumes it). Rules support presets, clock, or a custom message,
    overnight windows (start > end belongs to the day it starts), per-rule
    enable, and priority by list order. Editor lives in the settings sheet;
    an active rule borrows the door badge as "Lunch · scheduled 58:12".
    Full-list replace via POST /api/state {"schedules": [...]}; demo
    spectators get an empty list.
    [app.py]
2026-07-11 Add a screen designer: draw pixels on the phone, send to the panel
    A bottom-sheet pixel editor for the 64x32 panel — draw/fill/erase with a
    panel-safe palette, undo, clear, "copy sign" seeds the canvas from
    /preview.png, and up to six designs save to localStorage. Send posts a
    PNG to the existing /api/upload, so designs ride the manual-hold rules
    (hold timer, TTL, Auto) like any media. Zero backend changes.
2026-07-11 Add arcade mode: an animated retro-platformer screen
    An original procedurally-drawn side-scroller for the panel — brick
    ground, pipes, parallax clouds, blinking coins, and a runner in
    KnockBlock orange who jumps each pipe as it arrives. 64 frames, seamless
    128px world loop, generated once and cached like the dumpster fire.
    New "arcade" status wired through load/POST/quick-set and the renderer;
    "Game On · WORLD 6-4" button in the phone UI; /api/set/arcade for the
    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
2026-07-13 Add per-device themes: Glass, Workshop, and Clear
    Settings → Appearance picks one of three themes, stored in a kb_theme
    cookie that index() reads so the first paint is already themed (no
    flash). Workshop stays the default house style; Glass is dark navy with
    translucent blurred surfaces, blue primaries, and 16px radii; Clear is
    a light, high-contrast, system-font theme with visible focus rings for
    accessibility. Themes are CSS-variable swaps on [data-theme] plus a few
    component extras; the hardcoded 4px radius became --radius to allow it.
    [app.py]
2026-07-13 Add CLAUDE.md: working guidance for coding agents
    The load-bearing knowledge that isn't obvious from any single file: the
    one-lock state model and arbiter priority, the _load_state validation
    pattern for new keys, the four auth tiers and which endpoints are
    session-or-local only, the dev harness switches, the merge-to-main =
    deploy pipeline, and the voice/design rules.
2026-07-14 Show each status's real render on its button; one action grid
    New /thumb/<status>.png composes what a status would actually show —
    presets and the clock render live (the clock thumb tells real time),
    fire and arcade use their first frame — and every status button wears
    its thumbnail. This Is Fine and Game On move out of the GIFs section
    into the status grid, so everything that sets the sign lives in one
    place and rides the existing #grid tap delegation; the GIFs section
    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
2026-07-14 Add panel themes: Classic, Overworld, and Terminal
    A sign-wide panel_theme setting restyles how preset statuses draw on
    the LED matrix. Overworld floats the status on a colored block over the
    arcade world (each status hangs over its own stretch of the level);
    Terminal is a green-phosphor console — prompt, status in its own color,
    block cursor, scanlines. All original procedural art. Applies to the
    four presets only; custom messages, clock, focus, and media keep their
    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
2026-07-16 Add Moonlight: a whimsical quiet-hours scene for the sleep window
    The sleep window can now show a very dim night scene instead of a dark
    panel: crescent moon, stars twinkling on their own beats, and a sleeping
    cat exhaling z's that drift upward (8 frames, 1.5s each, deliberately
    faint so quiet hours stay quiet). New settings.sleep_scene ("dark",
    the unchanged default, or "moon") picked via chips under Sleep schedule;
    the sleep render signature includes the scene so switching repaints
    immediately, and the phone preview polls while the sign sleeps.
    [app.py, media.py]
2026-07-16 Add custom statuses: build and remove your own status buttons
    A "+ New status" tile in the grid opens an editor: text over a panel
    color (rendered like a custom message, leading emoji becomes the icon)
    or captioned fire-style over an uploaded image/meme/GIF. Up to 8; they
    join the grid with real-render thumbnails, set like any status (incl.
    /api/set/cs_… for the Stream Deck), persist in state with background
    files in media/ (untracked, so they survive self-updates), and deleting
    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
2026-07-16 Add GIF search-and-pick, for the panel and status backgrounds
    Enter in the GIF box now searches Tenor/Giphy and shows a grid of
    candidates; tapping one plays it on the panel under the usual hold
    rules (Roll stays random). The new-status editor gets the same picker,
    so a meme background no longer requires downloading it first. New
    GET /api/gif/search; POST /api/gif and /api/statuses accept a picked
    url — downloads are allowlisted to the providers' own CDNs so the
    endpoint can't proxy arbitrary hosts. Dev harness gains offline GIF
    fixtures (KNOCKBLOCK_DEV_FAKE_GIFS) since the old public demo keys have
    gone stale; README notes a personal Giphy key is now the reliable path.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
    [app.py, media.py]
2026-07-16 Add the 8-bit panel style; status buttons wear their screens; demo drives
    Three changes, one theme: what you tap is what the door shows.
    - New "8-bit" panel style: pixel-icon dialog cards for every screen —
    headset, sun, meeting heads, and do-not-enter icons for the presets,
    and (a first for panel styles) matching clock and focus screens: sun
    or moon by hour, hourglass countdown. Original pixel art, bbox-exact
    text fitting so nothing kisses the frame.
    - Status buttons redesigned: the full-bleed background IS the status's
    real render, with a 10px vertical name tab on the left edge and a
    CURRENT badge; every cell (presets, fire, arcade, clock, customs, the
    new-status tile) is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
    [app.py, panel_themes.py]
2026-07-16 Fix a missing quote in the new preset colors
    The color/emoji update left "#A81919 unterminated, which is a
    SyntaxError — the app wouldn't import, and self-update would roll back.
    Values untouched.
    [presets.py]
2026-07-17 Bare-GIF statuses, the Nameplate style, and a proper Timers card
    - Custom statuses can drop the caption: a "Caption the image with the
    text" switch in the editor — off, the GIF plays bare and the text just
    names the button. Backward compatible (missing flag = captioned).
    - The Overworld panel style gives way to Nameplate: skeuomorphic
    brushed-metal shop plates with beveled edges, corner screws, engraved
    status text, and a glowing indicator lamp in the status color. Old
    saved "overworld" settings fall back to Classic via the usual
    validation.
    - Timers get the prominence they earn: a bordered card right under the
    sticky door preview (pick a duration, then tap a status — that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
    [app.py, media.py, panel_themes.py]
2026-07-21 Add a screen-off power control; schedule any screen; round toggles
    - Screen off: a power button in the header turns the panel fully dark on
    demand. It's a manual "screen_off" hold — top priority, so it overrides
    the nightly schedule and whatever is showing — and it holds forever
    (never auto-reverts on the default TTL; a dark hallway shouldn't relight
    itself). Tapping any status or the badge wakes it. Also on the API and
    /api/set/screen_off for the Stream Deck; survives a restart.
    - Scheduled statuses can now assign any screen: presets, clock, dumpster
    fire, arcade, and your own custom/GIF screens (a live "Your screens"
    group in the rule editor). Deleting a custom screen pru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
    [app.py]
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2026-07-21 Swap the Glass accent from teal to brand red (#de1925)
    Primary actions, the active/now indicator, and the wordmark now use
    #de1925 on the airy light ground.
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2026-07-23 Fix persistent hold behavior
    [app.py]
2026-09-24 Add printable dual-panel enclosure and diffuser
    [knockblock_back_shell.stl, knockblock_bezel.stl, knockblock_case.scad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]
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
